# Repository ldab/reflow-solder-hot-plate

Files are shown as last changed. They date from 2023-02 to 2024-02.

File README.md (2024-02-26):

# reflow-solder-hot-plate
 USB-C powered, esp32s3 based, hot plate







<p align="center">
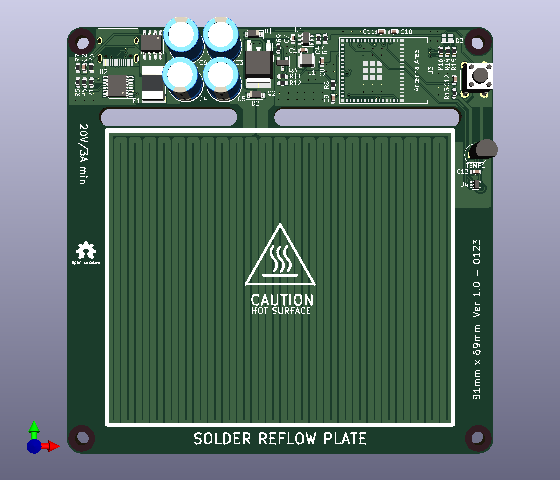
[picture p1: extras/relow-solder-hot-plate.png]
  
</p>

<p align="center">
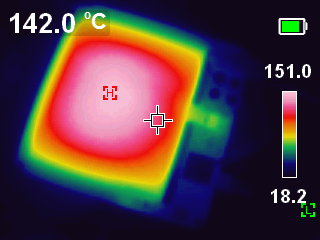
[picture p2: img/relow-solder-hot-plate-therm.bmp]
  
</p>

## Before anything else:

:exclamation: :boom:

Make sure you understand the risks involved on this project as you will be dealing with high temperatures and high-ish voltages.

It is important that the power supply used is able to supply enough current, otherwise it will crash, if you got the board from me it should be fine, otherwise adjust the values on `lib/temp_control/temp_control.h`

### TODO

* Save readings on a vector so it reloads the graph in case you leave the webpage;
* Websocket terminal;
* Use the button to trigger reflow;

### Main CPU

I used the the following board because that is what I had on my drawer:

### Reflow profile

It takes 3x temperature "profiles" as arguments, just to keep it simple

<p align="center">
  
</p>

### Duty cycle and Supply current

With a duty cycle of 78% (PWM is inverted), it results in 22% of the total power and at 20V it should draw ~2.16A

<p align="center">
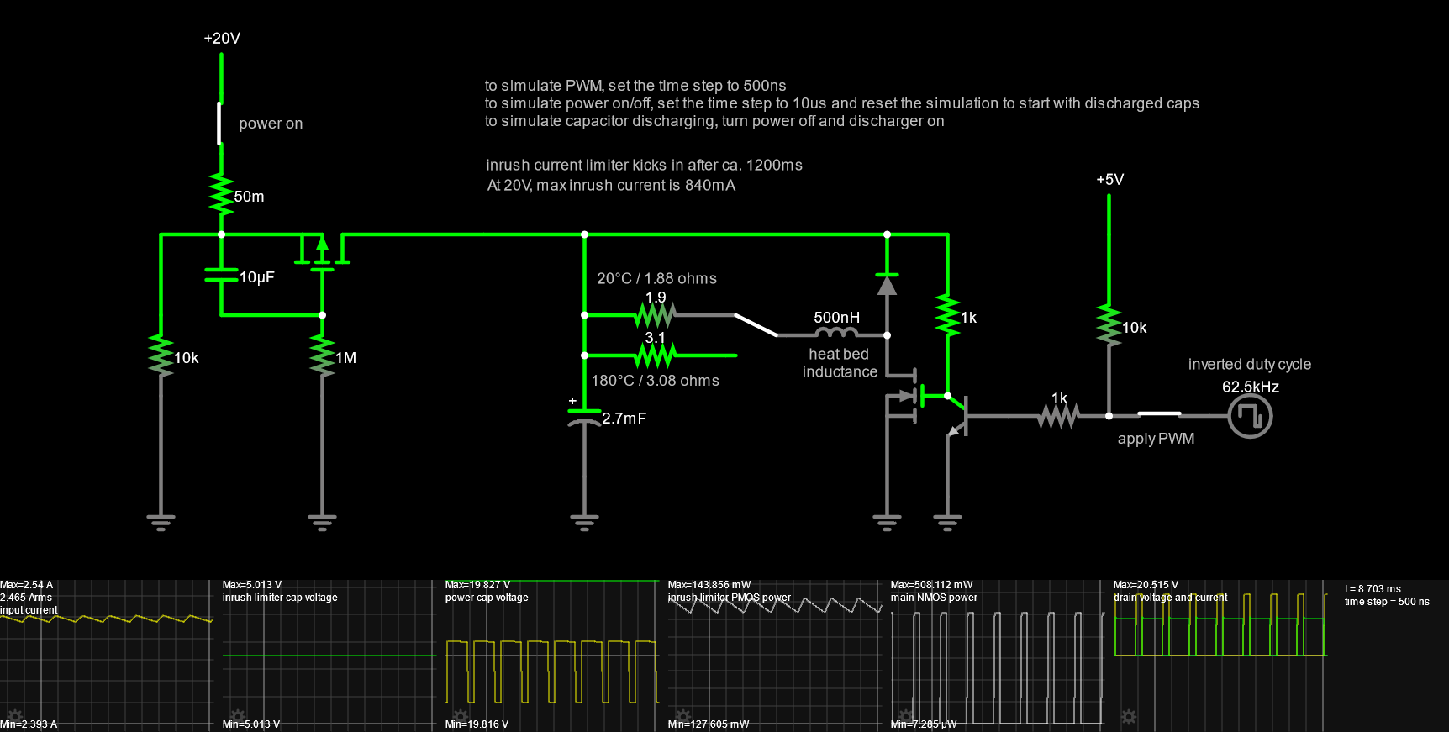
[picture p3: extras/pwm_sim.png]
  
</p>

https://tinyurl.com/2pvo2wyf

### Known issues

* Because of the mosfet logic and high current, when plugged to the computer, the USB-A port will probably struggle to deliver power and will rover around 3.6V, which is not enough to feed the Buck-Converter, that will result in the ESP32 to not wake up and the Mosfet will be constantly ON :exclamation: :exclamation: :exclamation:

* For the reason mentioned above, it need to be programed via RX/TX test points under the board;

* RX connects to RX and TX connects to TX :disappointed:

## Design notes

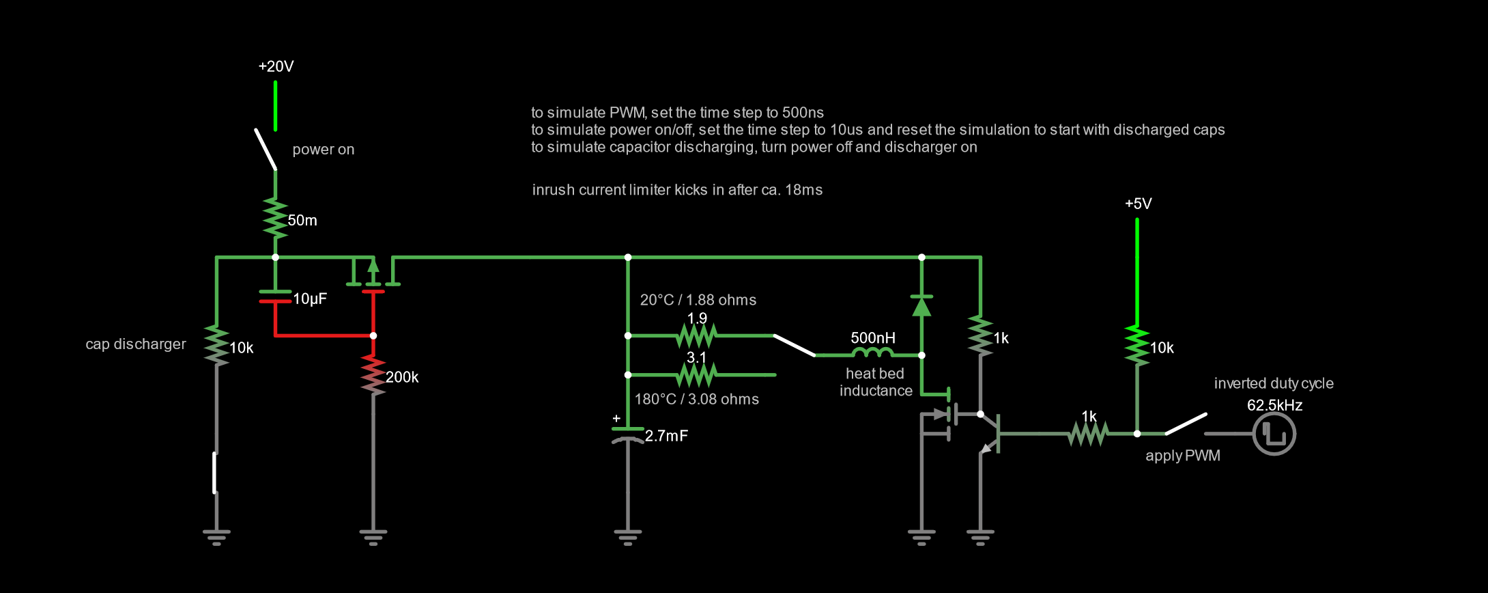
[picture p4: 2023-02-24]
img/circuit-20230106-1142.png

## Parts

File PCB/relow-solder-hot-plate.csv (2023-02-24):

Column1 | Column2 | Column3 | Column4 | Column5 | Column6 | Column10 | Column11 | Column12 | Column13
Source: | C:\PERSONAL\relow-solder-hot-plate\PCB\relow-solder-hot-plate.kicad_sch
Date: | 2023-01-09 21:39:56
Tool: | Eeschema (6.0.1)
Generator: | C:\Program Files\KiCad\6.0\bin\scripting\plugins/bom_csv_grouped_by_value.py
Component Count: | 49
Individual Components:
Item | Qty | Reference(s) | Value | LibPart | Footprint | LCSC | LCSC Part Number | LCSC Part Number Alternative | PN
 |  | C1 | 100n | Device:C_Small | Capacitor_SMD:C_0603_1608Metric | C338036
 |  | C2 | 10u | Device:C_Small | Capacitor_SMD:C_0603_1608Metric | C87152 |  |  | JMK107BJ106MA-T
 |  | C3 | 680u/16V | Device:C_Polarized_Small | Capacitor_THT:CP_Radial_D8.0mm_P3.50mm | C88760 | C88760 | C124221
 |  | C4 | 680u/16V | Device:C_Polarized_Small | Capacitor_THT:CP_Radial_D8.0mm_P3.50mm | C88760 | C88760 | C124221
 |  | C5 | 680u/16V | Device:C_Polarized_Small | Capacitor_THT:CP_Radial_D8.0mm_P3.50mm | C88760 | C88760 | C124221
 |  | C6 | 680u/16V | Device:C_Polarized_Small | Capacitor_THT:CP_Radial_D8.0mm_P3.50mm | C88760 | C88760 | C124221
 |  | C7 | 10u | Device:C_Small | Capacitor_SMD:C_0603_1608Metric | C87152 |  |  | JMK107BJ106MA-T
 |  | C8 | 10u | Device:C_Small | Capacitor_SMD:C_0603_1608Metric | C87152 |  |  | JMK107BJ106MA-T
 |  | C9 | 100n | Device:C_Small | Capacitor_SMD:C_0603_1608Metric | C338036
 |  | C10 | 10u | Device:C_Small | Capacitor_SMD:C_0603_1608Metric | C87152 |  |  | JMK107BJ106MA-T
 |  | C11 | 100n | Device:C_Small | Capacitor_SMD:C_0603_1608Metric | C338036
 |  | C12 | 100n | Device:C_Small | Capacitor_SMD:C_0603_1608Metric | C338036
 |  | D1 | B5819W | Device:D_Small_Filled | Diode_SMD:D_SOD-123 | C64885 | C64885 | C109213
 |  | D2 | B5819W | Device:D_Small_Filled | Diode_SMD:D_SOD-123 | C64885 | C64885 | C109213
 |  | D3 | LED_RBAG | Device:LED_RBAG | LED_SMD:LED_Cree-PLCC4_2x2mm_CW | C108793
 |  | F1 | 3A | Device:Polyfuse_Small | Fuse:Fuse_2920_7451Metric | C841188 | C841188 | C841188
 |  | H1 | M3 | Mechanical:MountingHole | MountingHole:MountingHole_3.2mm_M3 | C551332 | C551332 | C357543
 |  | H2 | M3 | Mechanical:MountingHole | MountingHole:MountingHole_3.2mm_M3 | C551332 | C551332 | C357543
 |  | H3 | M3 | Mechanical:MountingHole | MountingHole:MountingHole_3.2mm_M3 | C551332 | C551332 | C357543
 |  | H4 | M3 | Mechanical:MountingHole | MountingHole:MountingHole_3.2mm_M3 | C551332 | C551332 | C357543
 |  | J1 | USB_C_Receptacle | Connector:USB_C_Receptacle | Connector_USB:USB_C_Receptacle_HRO_TYPE-C-31-M-12
 |  | L1 | 4.7u | Device:L_Small | Inductor_SMD:L_1210_3225Metric | C90319
 |  | Q1 | WSP4409A | User:Q_PMOS_SSSGDDDD | Package_SO:SOIC-8_3.9x4.9mm_P1.27mm | C2880527 | C2880527 | C54807
 |  | Q2 | IRLR8726TRPBF | Device:Q_NMOS_GDS | Package_TO_SOT_SMD:TO-252-2 | C81137 | C81137 | C108901
 |  | Q3 | SS8050 | Device:Q_NPN_BEC | Package_TO_SOT_SMD:SOT-23 | C444722 | C444722 | C2150
 |  | R1 | 100K | Device:R_Small | Resistor_SMD:R_0603_1608Metric | C2907088
 |  | R2 | 100K | Device:R_Small | Resistor_SMD:R_0603_1608Metric | C2907088
 |  | R3 | 10K | Device:R_Small | Resistor_SMD:R_0603_1608Metric | C17414 | C17414 | C17414
 |  | R4 | 22K | Device:R_Small | Resistor_SMD:R_0603_1608Metric | C2907128
 |  | R5 | 5K1 | Device:R_Small | Resistor_SMD:R_0603_1608Metric | C14677
 |  | R6 | 5K1 | Device:R_Small | Resistor_SMD:R_0603_1608Metric | C14677
 |  | R7 | 200K | Device:R_Small | Resistor_SMD:R_0603_1608Metric | C5140968
 |  | R8 | 1K | Device:R_Small | Resistor_SMD:R_0603_1608Metric | C384295 | C384295 | C384295
 |  | R9 | 5K1 | Device:R_Small | Resistor_SMD:R_0603_1608Metric | C14677
 |  | R11 | 10k | Device:R_Small | Resistor_SMD:R_0603_1608Metric | C17414 | C17414 | C84376
 |  | R12 | 1k | Device:R_Small | Resistor_SMD:R_0603_1608Metric | C384295 | C384295 | C384295
 |  | R13 | 10K | Device:R_Small | Resistor_SMD:R_0603_1608Metric | C17414 | C17414 | C17414
 |  | R14 | 1K | Device:R_Small | Resistor_SMD:R_0603_1608Metric | C384295 | C384295 | C384295
 |  | R15 | 1K | Device:R_Small | Resistor_SMD:R_0603_1608Metric | C384295 | C384295 | C384295
 |  | R16 | 1K | Device:R_Small | Resistor_SMD:R_0603_1608Metric | C384295 | C384295 | C384295
 |  | SW1 | SW_Push | Switch:SW_Push | Button_Switch_THT:SW_PUSH_6mm_H4.3mm | C499289
 |  | TEMP1 | LMT85 | Sensor_Temperature:LM35-LP | Package_TO_SOT_THT:TO-92_Inline | C75856 | C75856
 |  | TEMP2 | LMT85 | Sensor_Temperature:LM35-LP | Package_SO:Texas_R-PDSO-N5 | C75856 | C75856
 |  | TP1 | TestPoint | Connector:TestPoint | TestPoint:TestPoint_Pad_D1.5mm
 |  | TP2 | TestPoint | Connector:TestPoint | TestPoint:TestPoint_Pad_D1.5mm
 |  | TP3 | TestPoint | Connector:TestPoint | TestPoint:TestPoint_Pad_D1.5mm
 |  | U1 | DIO6912 | lib:DIO6912 | Package_TO_SOT_SMD:SOT-23-6 | C444642
 |  | U2 | IP2721 | User:IP2721 | Package_SO:TSSOP-16_4.4x5mm_P0.65mm | C603176 | C603176 | -
 |  | U3 | ESP32-S3-MINI-1 | Espressif:ESP32-S3-MINI-1 | Espressif:ESP32-S3-MINI-1 | C2913206
Collated Components:
Item | Qty | Reference(s) | Value | LibPart | Footprint | LCSC | LCSC Part Number | LCSC Part Number Alternative | PN
1 | 4 | C1, C9, C11, C12 | 100n | Device:C_Small | Capacitor_SMD:C_0603_1608Metric | C338036
2 | 4 | C2, C7, C8, C10 | 10u | Device:C_Small | Capacitor_SMD:C_0603_1608Metric | C87152 |  |  | JMK107BJ106MA-T
3 | 4 | C3, C4, C5, C6 | 680u/16V | Device:C_Polarized_Small | Capacitor_THT:CP_Radial_D8.0mm_P3.50mm | C88760 | C88760 | C124221
4 | 2 | D1, D2 | B5819W | Device:D_Small_Filled | Diode_SMD:D_SOD-123 | C64885 | C64885 | C109213
5 | 1 | D3 | LED_RBAG | Device:LED_RBAG | LED_SMD:LED_Cree-PLCC4_2x2mm_CW | C108793
6 | 1 | F1 | 3A | Device:Polyfuse_Small | Fuse:Fuse_2920_7451Metric | C841188 | C841188 | C841188
7 | 4 | H1, H2, H3, H4 | M3 | Mechanical:MountingHole | MountingHole:MountingHole_3.2mm_M3 | C551332 | C551332 | C357543
8 | 1 | J1 | USB_C_Receptacle | Connector:USB_C_Receptacle | Connector_USB:USB_C_Receptacle_HRO_TYPE-C-31-M-12
9 | 1 | L1 | 4.7u | Device:L_Small | Inductor_SMD:L_1210_3225Metric | C90319
10 | 1 | Q1 | WSP4409A | User:Q_PMOS_SSSGDDDD | Package_SO:SOIC-8_3.9x4.9mm_P1.27mm | C2880527 | C2880527 | C54807
11 | 1 | Q2 | IRLR8726TRPBF | Device:Q_NMOS_GDS | Package_TO_SOT_SMD:TO-252-2 | C81137 | C81137 | C108901
12 | 1 | Q3 | SS8050 | Device:Q_NPN_BEC | Package_TO_SOT_SMD:SOT-23 | C444722 | C444722 | C2150
13 | 2 | R1, R2 | 100K | Device:R_Small | Resistor_SMD:R_0603_1608Metric | C2907088
14 | 2 | R3, R13 | 10K | Device:R_Small | Resistor_SMD:R_0603_1608Metric | C17414 | C17414 | C17414
15 | 1 | R4 | 22K | Device:R_Small | Resistor_SMD:R_0603_1608Metric | C2907128
16 | 3 | R5, R6, R9 | 5K1 | Device:R_Small | Resistor_SMD:R_0603_1608Metric | C14677
17 | 1 | R7 | 200K | Device:R_Small | Resistor_SMD:R_0603_1608Metric | C5140968
18 | 4 | R8, R14, R15, R16 | 1K | Device:R_Small | Resistor_SMD:R_0603_1608Metric | C384295 | C384295 | C384295
19 | 1 | R11 | 10k | Device:R_Small | Resistor_SMD:R_0603_1608Metric | C17414 | C17414 | C84376
20 | 1 | R12 | 1k | Device:R_Small | Resistor_SMD:R_0603_1608Metric | C384295 | C384295 | C384295
21 | 1 | SW1 | SW_Push | Switch:SW_Push | Button_Switch_THT:SW_PUSH_6mm_H4.3mm | C499289
22 | 1 | TEMP1 | LMT85 | Sensor_Temperature:LM35-LP | Package_TO_SOT_THT:TO-92_Inline | C75856 | C75856
23 | 1 | TEMP2 | LMT85 | Sensor_Temperature:LM35-LP | Package_SO:Texas_R-PDSO-N5 | C75856 | C75856
24 | 3 | TP1, TP2, TP3 | TestPoint | Connector:TestPoint | TestPoint:TestPoint_Pad_D1.5mm
25 | 1 | U1 | DIO6912 | lib:DIO6912 | Package_TO_SOT_SMD:SOT-23-6 | C444642
26 | 1 | U2 | IP2721 | User:IP2721 | Package_SO:TSSOP-16_4.4x5mm_P0.65mm | C603176 | C603176 | -
27 | 1 | U3 | ESP32-S3-MINI-1 | Espressif:ESP32-S3-MINI-1 | Espressif:ESP32-S3-MINI-1 | C2913206

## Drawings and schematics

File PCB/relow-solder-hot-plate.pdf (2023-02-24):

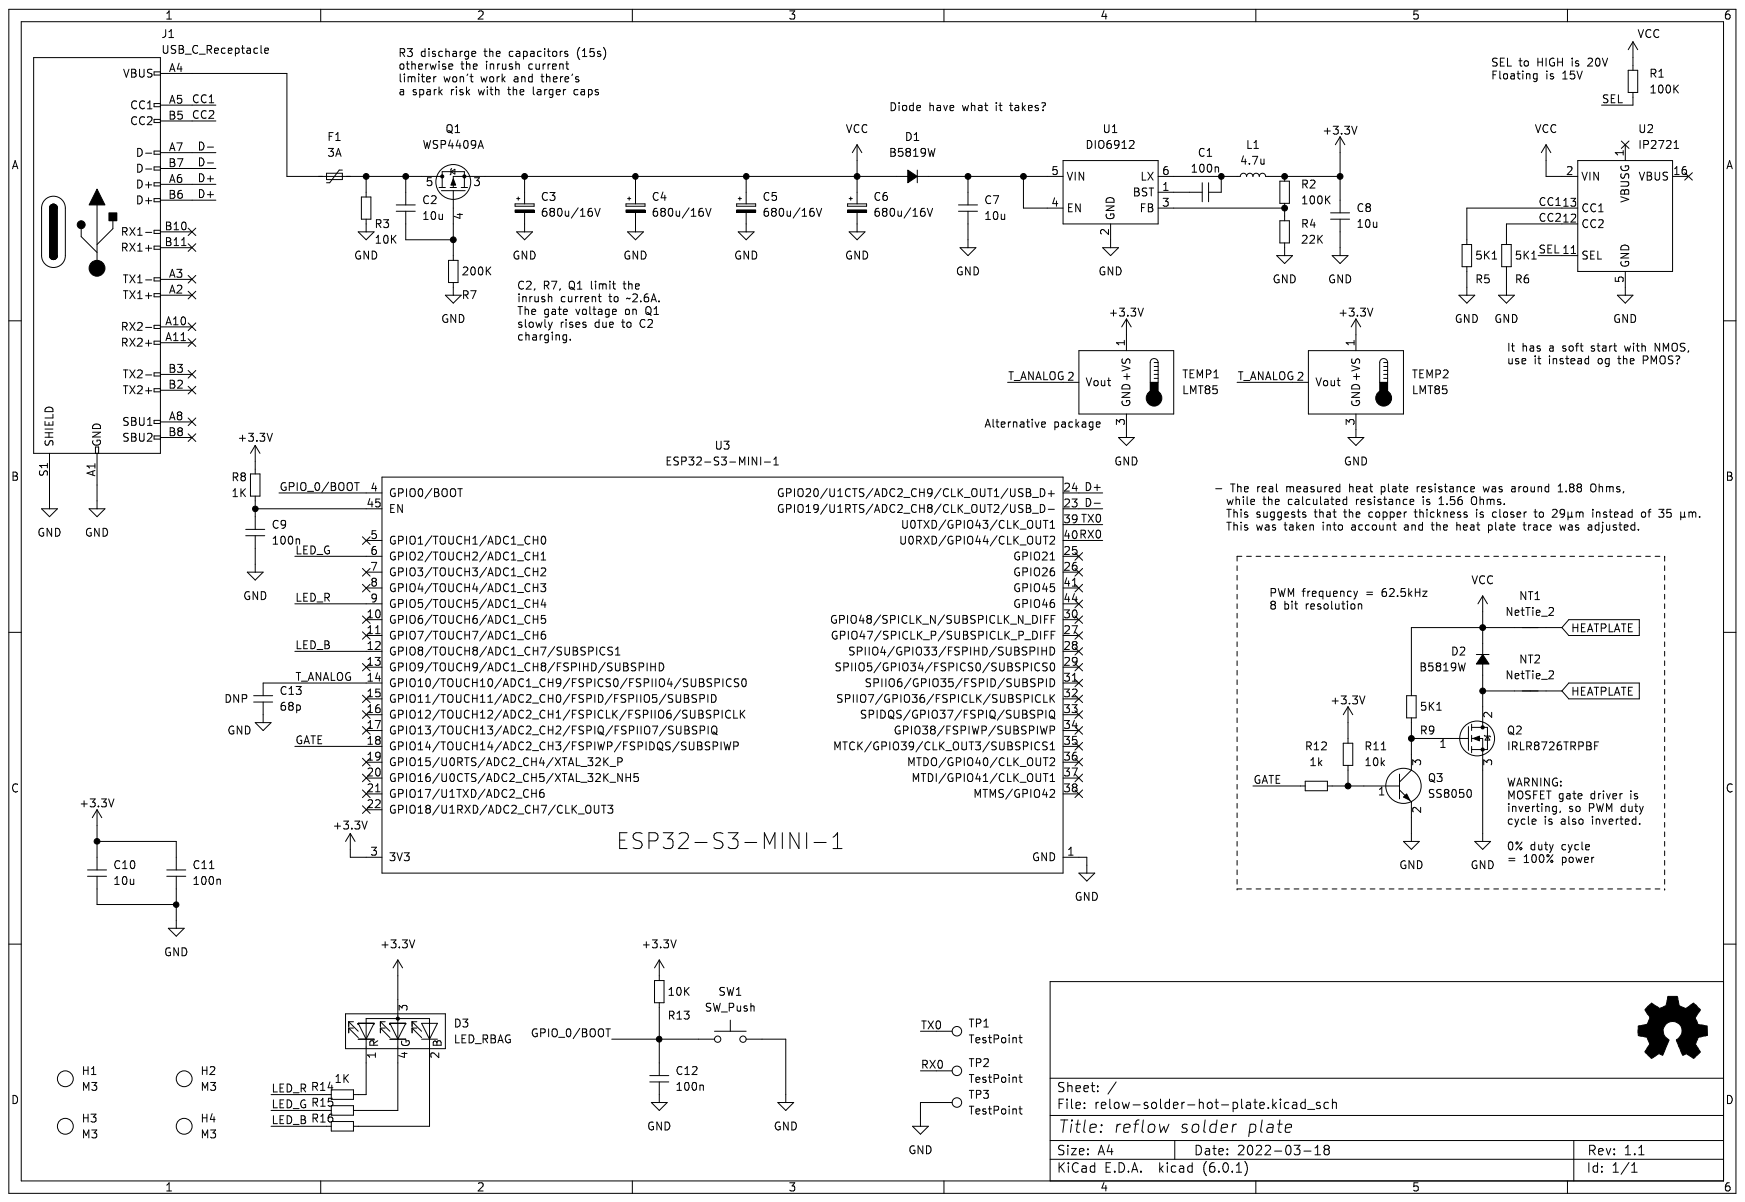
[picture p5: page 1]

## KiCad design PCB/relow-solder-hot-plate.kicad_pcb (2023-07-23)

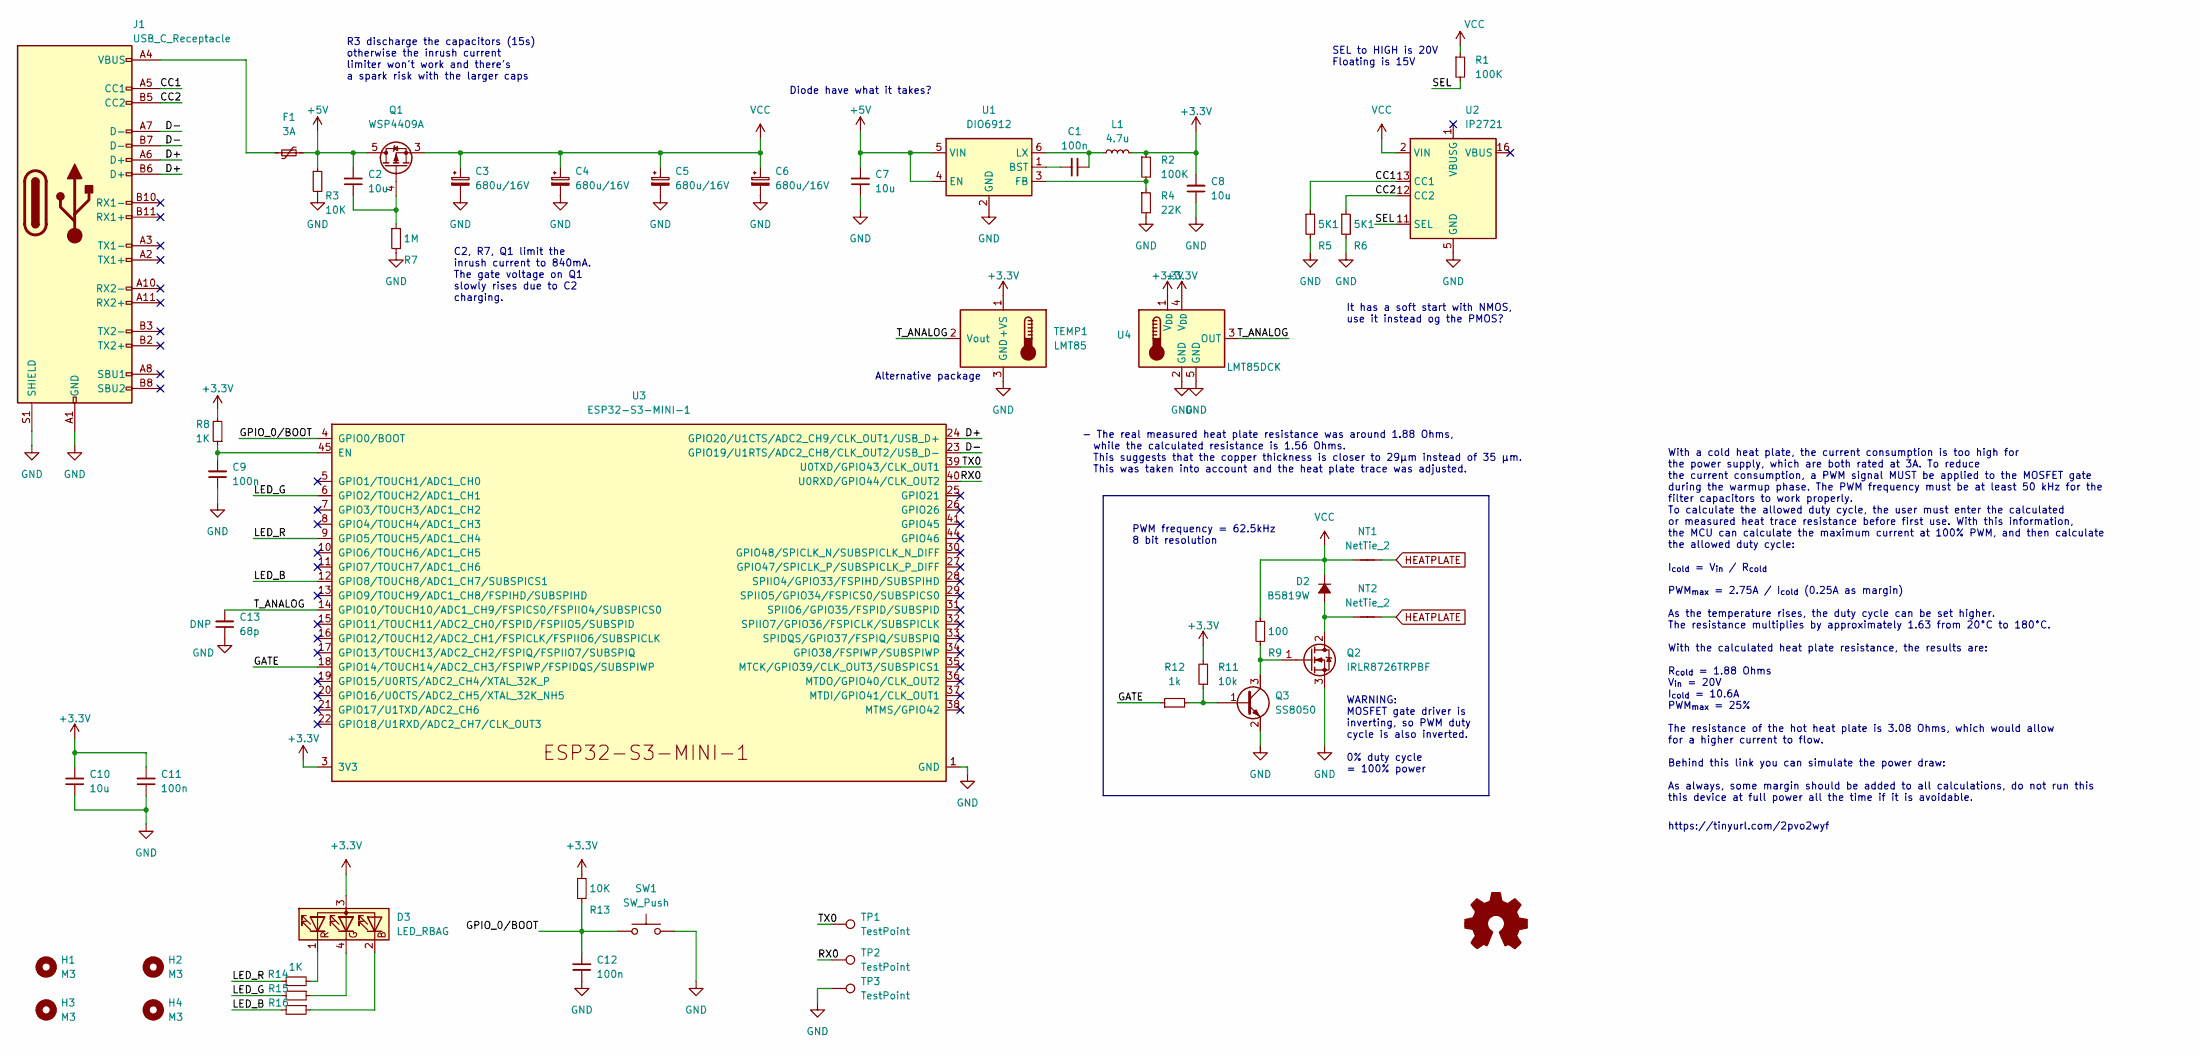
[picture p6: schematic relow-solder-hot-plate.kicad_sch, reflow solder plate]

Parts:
C1, C9, C11, C12: 100n; C_0603_1608Metric; LCSC C338036
C2, C7, C8, C10: 10u; C_0603_1608Metric; LCSC C87152
C3, C4, C5, C6: 680u/16V; CP_Radial_D8.0mm_P3.50mm; LCSC Part Number C88760
C13: 68p; C_0603_1608Metric; LCSC C162261
D2: B5819W; D_SOD-123; LCSC Part Number C64885
D3: LED_RBAG; LED_Cree-PLCC4_2x2mm_CW; LCSC C108793
F1: 3A; Fuse_2920_7451Metric; LCSC Part Number C841188
H1, H2, H3, H4: M3; MountingHole_3.2mm_M3; LCSC Part Number C551332
J1: USB_C_Receptacle; USB_C_Receptacle_HRO_TYPE-C-31-M-12
L1: 4.7u; L_1210_3225Metric; LCSC C90319
LOGO1: Logo_Open_Hardware_Small; OSHW-Logo2_7.3x6mm_SilkScreen
NT1, NT2: NetTie_2; NetTie-2_SMD_Pad1.3mm
Q1: WSP4409A; SOIC-8_3.9x4.9mm_P1.27mm; LCSC Part Number C2880527
Q2: IRLR8726TRPBF; TO-252-2; LCSC Part Number C81137
Q3: SS8050; SOT-23; LCSC Part Number C444722
R1, R2: 100K; R_0603_1608Metric; LCSC C2907088
R3, R13: 10K; R_0603_1608Metric; LCSC C17414
R4: 22K; R_0603_1608Metric; LCSC C2907128
R5, R6: 5K1; R_0603_1608Metric; LCSC C14677
R7: 1M; R_0603_1608Metric
R8, R14, R15, R16: 1K; R_0603_1608Metric; LCSC C384295
R9: 100; R_0603_1608Metric; LCSC C14677
R11: 10k; R_0603_1608Metric; LCSC Part Number C17414
R12: 1k; R_0603_1608Metric; LCSC Part Number C384295
SW1: SW_Push; SW_PUSH_6mm_H4.3mm; LCSC C499289
TEMP1: LMT85; TO-92_Inline; LCSC Part Number C75856
TP1, TP2, TP3: TestPoint; TestPoint_Pad_D1.5mm
U1: DIO6912; SOT-23-6; LCSC C444642
U2: IP2721; TSSOP-16_4.4x5mm_P0.65mm; JLCPCB basic part n
U3: ESP32-S3-MINI-1; LCSC C2913206
U4: LMT85DCK; SOT-353_SC-70-5

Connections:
+3V3: C8.2, C10.2, C11.2, D3.3 (A), L1.2, R2.1, R8.2, R11.2, R13.1, TEMP1.1 (+VS), U3.3 (3V3), U4.1 (V_{DD}), U4.4 (V_{DD})
+5V: C2.2, C7.2, F1.2, Q1.5 (D), Q1.6 (D), Q1.7 (D), Q1.8 (D), R3.1, U1.4 (EN), U1.5 (VIN)
/CC1: J1.A5 (CC1), R5.1, U2.13 (CC1)
/CC2: J1.B5 (CC2), R6.1, U2.12 (CC2)
/D+: J1.A6 (D+), J1.B6 (D+), U3.24 (GPIO20/U1CTS/ADC2_CH9/CLK_OUT1/USB_D+)
/D-: J1.A7 (D-), J1.B7 (D-), U3.23 (GPIO19/U1RTS/ADC2_CH8/CLK_OUT2/USB_D-)
/GATE: R12.1, U3.18 (GPIO14/TOUCH14/ADC2_CH3/FSPIWP/FSPIDQS/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)
/GPIO_0/BOOT: C12.2, R13.2, SW1.1, U3.4 (GPIO0/BOOT)
/LED_B: R16.2, U3.12 (GPIO8/TOUCH8/ADC1_CH7/SUBSPICS1)
/LED_G: R15.2, U3.6 (GPIO2/TOUCH2/ADC1_CH1)
/LED_R: R14.1, U3.9 (GPIO5/TOUCH5/ADC1_CH4)
/RX0: TP2.1, U3.40 (U0RXD/GPIO44/CLK_OUT2)
/SEL: R1.2, U2.11 (SEL)
/TX0: TP1.1, U3.39 (U0TXD/GPIO43/CLK_OUT1)
/T_ANALOG: C13.2, TEMP1.2 (Vout), U3.14 (GPIO10/TOUCH10/ADC1_CH9/FSPICS0/FSPIIO4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), U4.3 (OUT)
GND: C3.2, C4.2, C5.2, C6.2, C7.1, C8.1, C9.1, C10.1, C11.1, C12.1, C13.1, J1.A1 (GND), J1.A12 (GND), J1.B1 (GND), J1.B12 (GND), J1.S1 (SHIELD), Q2.3 (S), Q3.2 (E), R3.2, R4.2, R5.2, R6.2, R7.2, SW1.2, TEMP1.3 (GND), TP3.1, U1.2 (GND), U2.5 (GND), U3.1 (GND), U3.2 (GND), U3.42 (GND), U3.43 (GND), U3.46 (GND), U3.47 (GND), U3.48 (GND), U3.49 (GND), U3.50 (GND), U3.51 (GND), U3.52 (GND), U3.53 (GND), U3.54 (GND), U3.55 (GND), U3.56 (GND), U3.57 (GND), U3.58 (GND), U3.59 (GND), U3.60 (GND), U3.61 (GND), U3.62 (GND), U3.63 (GND), U3.64 (GND), U3.65 (GND), U4.2 (GND), U4.5 (GND)
HEATPLATE: NT1.2, NT2.2
unnamed: D2.2 (A), NT2.1, Q2.2 (D)
unnamed: D3.2 (BK), R16.1
unnamed: D3.4 (GK), R15.1
unnamed: D3.1 (RK), R14.2
unnamed: F1.1, J1.A4 (VBUS), J1.A9 (VBUS), J1.B4 (VBUS), J1.B9 (VBUS)
unnamed: C2.1, Q1.4 (G), R7.1
unnamed: Q2.1 (G), Q3.3 (C), R9.2
unnamed: Q3.1 (B), R11.1, R12.2
unnamed: C1.2, U1.1 (BST)
unnamed: R2.2, R4.1, U1.3 (FB)
unnamed: C1.1, L1.1, U1.6 (LX)
unnamed: C9.2, R8.1, U3.45 (EN)
VCC: C3.1, C4.1, C5.1, C6.1, D2.1 (K), NT1.1, Q1.1 (S), Q1.2 (S), Q1.3 (S), R1.1, R9.1, U2.2 (VIN)

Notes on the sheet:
C2, R7, Q1 limit the inrush current to 840mA. The gate voltage on Q1 slowly rises due to C2 charging.
Alternative package
PWM frequency = 62.5kHz 8 bit resolution
With a cold heat plate, the current consumption is too high for the power supply, which are both rated at 3A. To reduce the current consumption, a PWM signal MUST be applied to the MOSFET gate during the warmup phase. The PWM frequency must be at least 50 kHz for the filter capacitors to work prope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
It has a soft start with NMOS, use it instead og the PMOS?
WARNING: MOSFET gate driver is inverting, so PWM duty cycle is also inverted. 0% duty cycle = 100% power
R3 discharge the capacitors (15s) otherwise the inrush current limiter won't work and there's a spark risk with the larger caps
https://tinyurl.com/2pvo2wyf
Diode have what it takes?
- The real measured heat plate resistance was around 1.88 Ohms, while the calculated resistance is 1.56 Ohms. This suggests that the copper thickness is closer to 29µm instead of 35 µm. This was taken into account and the heat plate trace was adjusted.
SEL to HIGH is 20V Floating is 15V

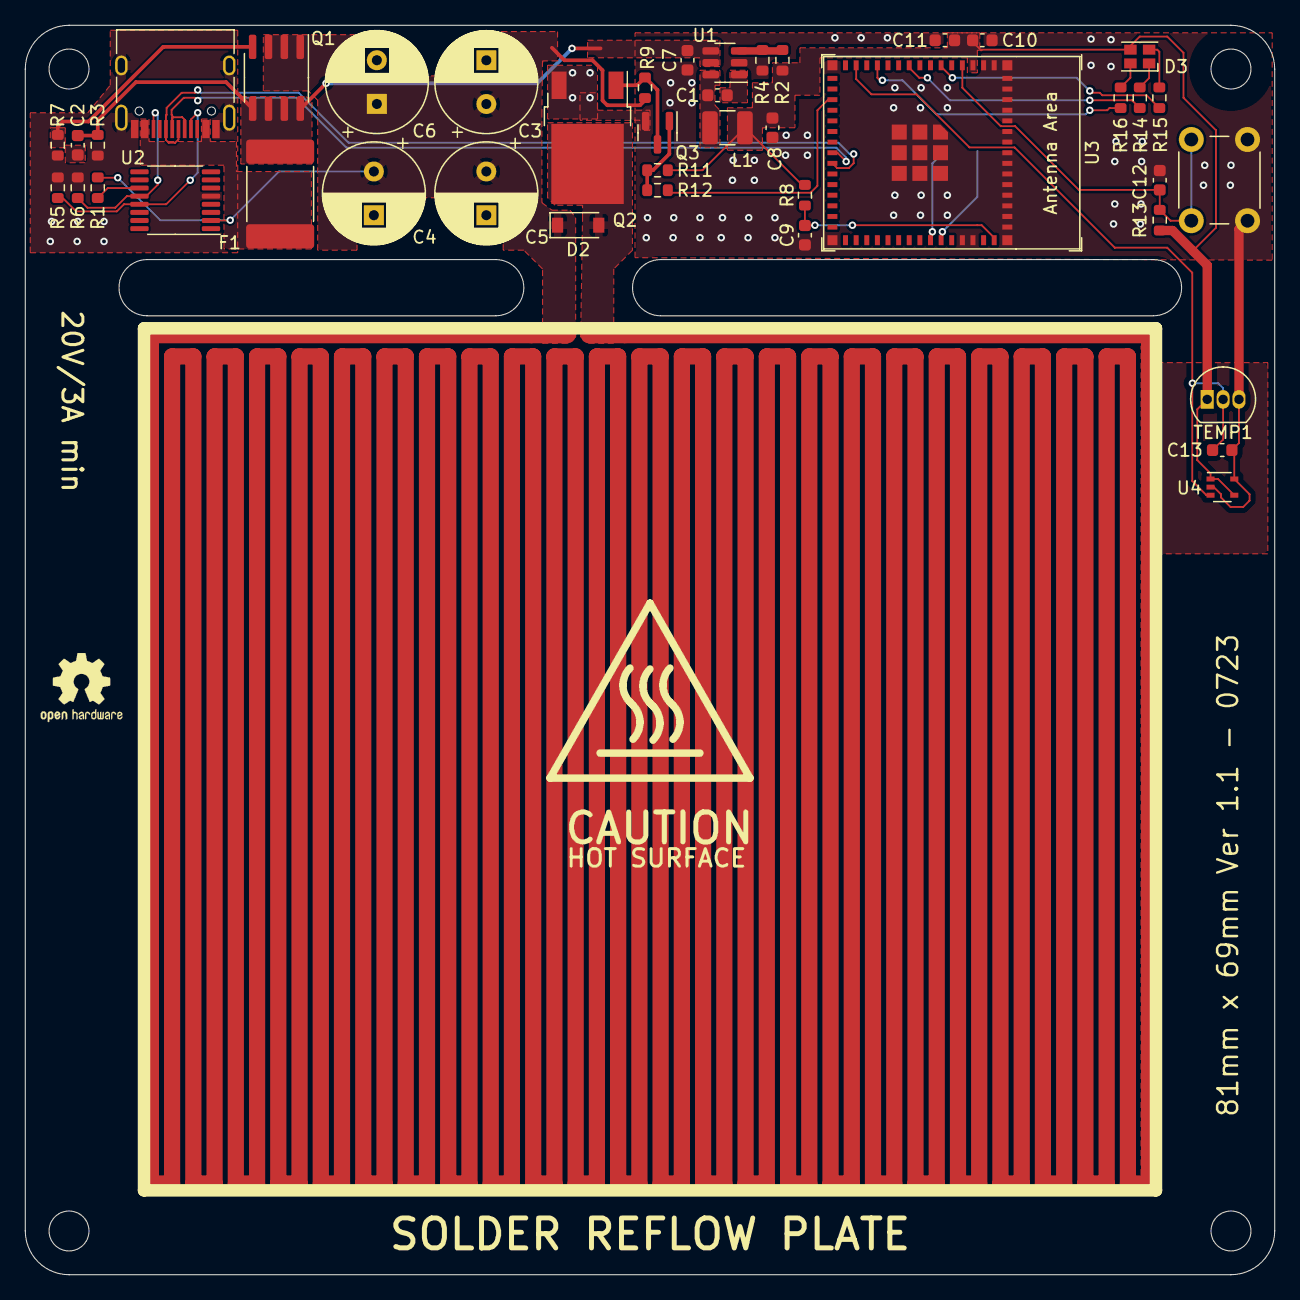
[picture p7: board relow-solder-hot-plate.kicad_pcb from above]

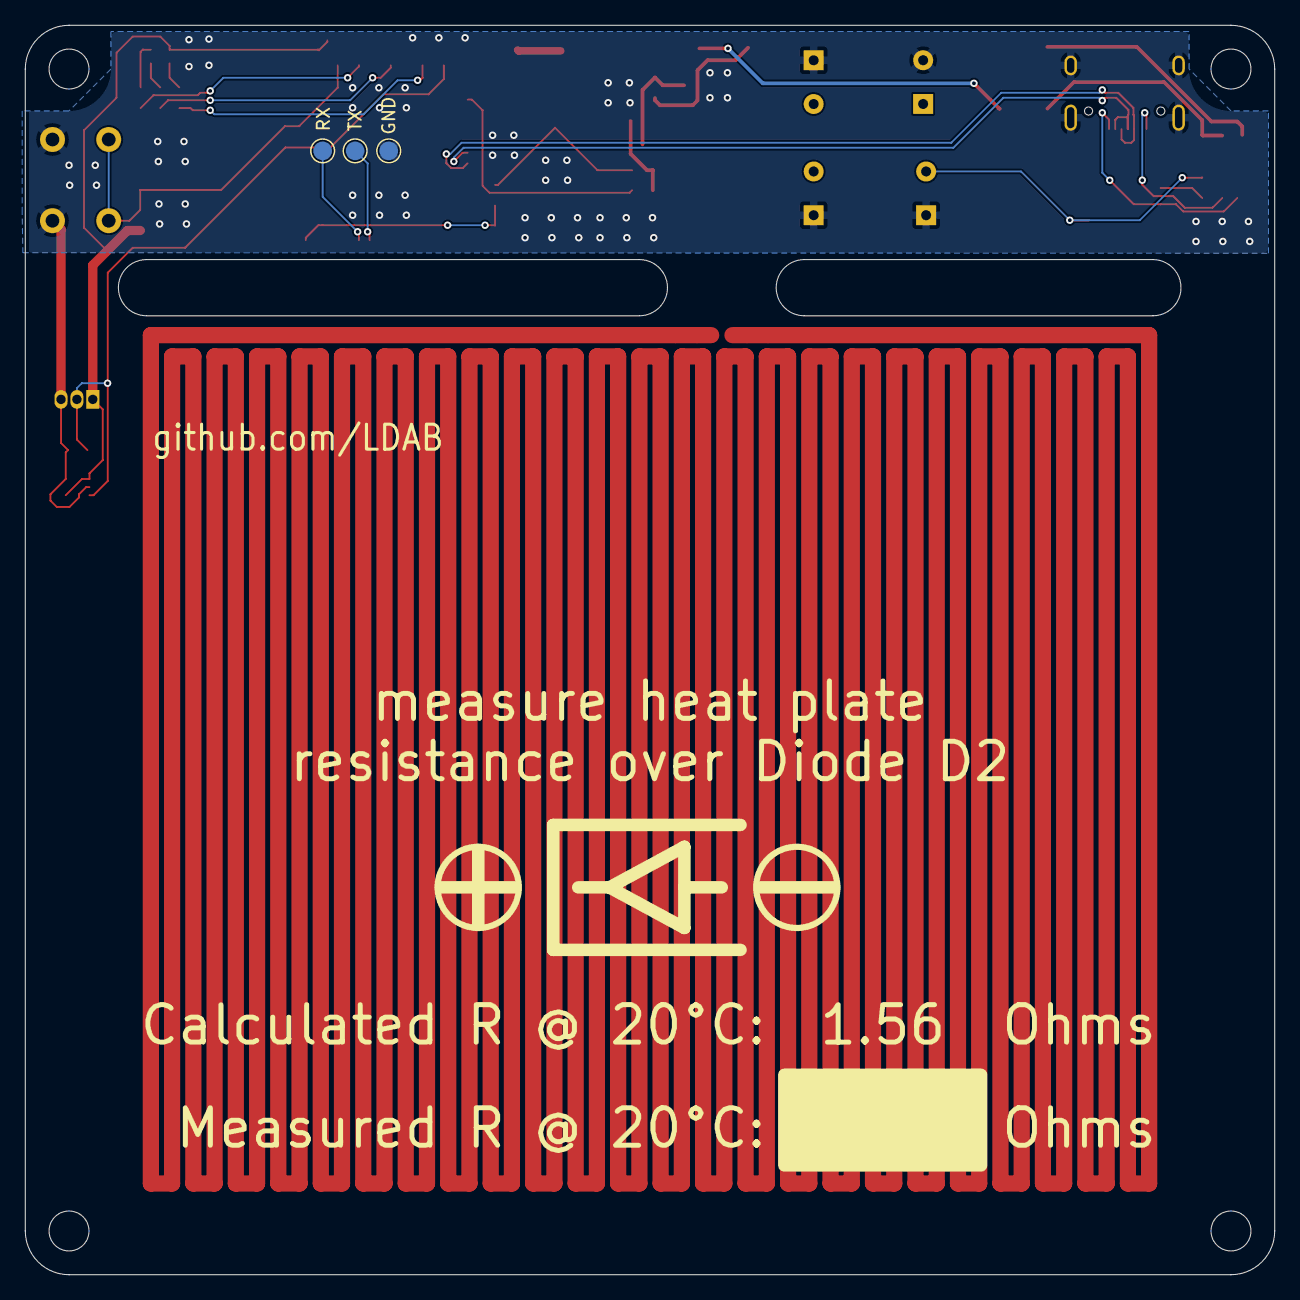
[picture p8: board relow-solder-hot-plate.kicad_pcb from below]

Board: 2 copper layers, 100.0 x 100.0 mm, 52 parts (3 on the bottom side), 30 nets.

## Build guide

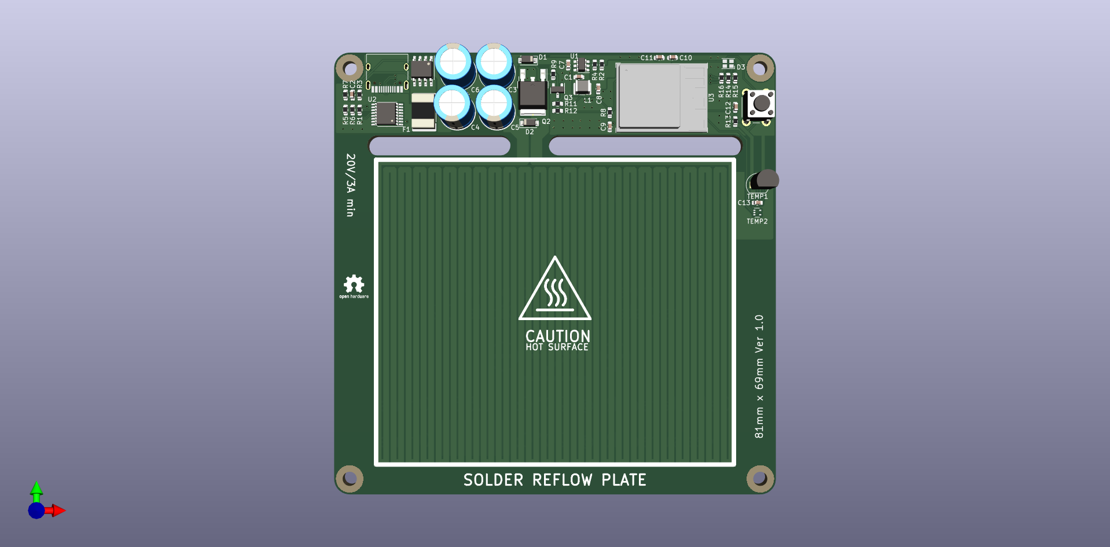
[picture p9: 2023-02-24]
img/relow-solder-hot-plate.png

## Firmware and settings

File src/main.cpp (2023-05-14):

#include <Arduino.h>

#include "gpio.h"
#include "lmt85.h"
#include "temp_control.h"
#include "webserver.h"

float temp     = 0;
uint8_t status = 0;

std::vector<float> readings;
std::vector<long> epocTime;

void webServerConnectedCb(void *profile)
{
  set_led(RED, SLOW);
  reflow_profile cfg;

  if (profile == NULL) {
    cfg = TEMP_CONTROL_DEFAULT();
  } else {
    cfg = *(reflow_profile *)profile;
  }

  temp_control_config(&cfg);

  temp_control_start(&temp);
}

void setup(void)
{
#ifdef CALIBRATE
  // Measure GPIO in order to determine Vref to gpio 25 or 26 or 27
  adc2_vref_to_gpio(GPIO_NUM_25);
  delay(5000);
  abort();
#endif

  gpios_init();

  Serial.begin(115200);
  log_i("APP version: %s", VERSION);

  // Serial.setDebugOutput(true);

  lmt85_init();
  lmt85_start(&temp);

  webserver_start(&readings, &epocTime, &temp, &webServerConnectedCb);
}

void loop(void) {}

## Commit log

2023-02-24 Hardware files (#1)
    [relow-solder-hot-plate-B_Cu.gbl, relow-solder-hot-plate-B_Mask.gbs, relow-solder-hot-plate-B_Paste.gbp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]
2023-03-19 Proto (#2)
    * FW draft
    * web server
    * draft gpios
    * lmt85
    * draft temp control
    * dry run
    * minor fix
    * LEDs are active LOW
    * inverted PWM
    * captive portal and webserver
    * Fix silkscreen and LMT85 footprint
    * fix adc attenuation
    * fix pwm frequency
    * minor fix
    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
    [relow-solder-hot-plate.kicad_pcb, relow-solder-hot-plate.kicad_sch]
2023-07-23 fix usb-c programmer
    [relow-solder-hot-plate.kicad_pcb, relow-solder-hot-plate.kicad_sch]

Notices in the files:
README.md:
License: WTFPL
